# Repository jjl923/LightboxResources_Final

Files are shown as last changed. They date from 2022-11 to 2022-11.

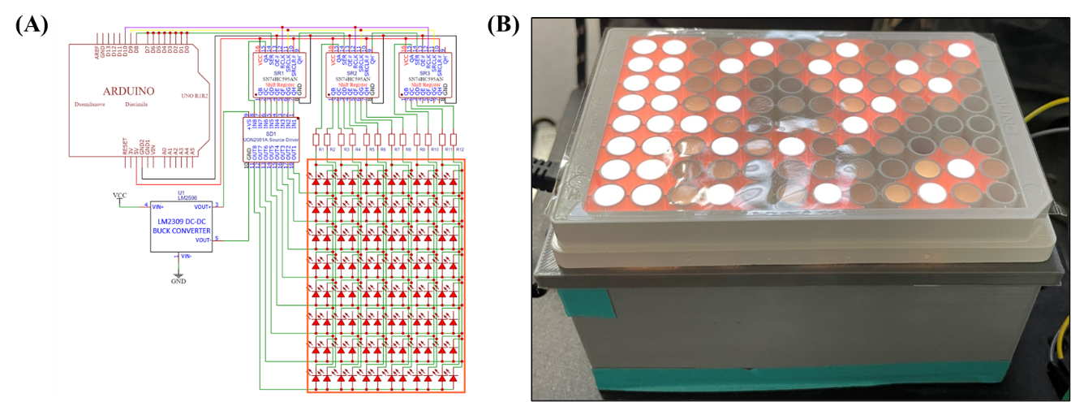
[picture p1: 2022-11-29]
Lightbox_Schematic.png

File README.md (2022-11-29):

# LightboxResources_Final

This repository contains all files necessary for building a lightbox with 96 multiplexed LEDS. To use any Python/Arduino scripts, ensure that the COM ports and fluorescence data file paths are changed to your specific setup. 

-STL Files are available for 3D printing a shell to contain all electronic components on the lightbox.

-Lightbox schematic shows the circuit diagram in which all components should be wired. 

-Python Files are used for fluorescence data analysis and sending data to the lightbox for lighting.
  - LightboxCalculator&Tester.py
    - tkinter interface that allows one to calculate the binary number to control each row of the lightbox. Click the LED in a row to be turned on, then click "Total". After doing so for each row, the final array should be input as "<a,b,c,d,r,f,g,h>" in the Python Script.
    
  - LBDataComm_NoFluorescence.py
    - Control the lighting profile of the lightbox using a manually input data array. Use the "LightboxCalculator&Tester.py" to determine the input array.
    
  - LBDataTest_FluorescenceXML.py
    - Use fluorescence data to control which LED is turned on. Two sets of sample data have been provided. Edit the clean_data() function and pass the file path of a given sample file.

  - FluorescenceAnalysisContinuous.ipynb
    - A jupyter notebook that can be used to continuously analyze sample data files in a given experiment. After running cells 1-3, cell 4 can be run over and over again with the sample file path name changed in order to simulate an automated fluorescence experiment. Of the sample data given, each experiment contains five timepoints with eight wells containing fluorescence data. So for example, run clean_data(r'C://...../SampleData1_1), then clean_data(r'C://...../SampleData1_2), then clean_data(r'C://...../SampleData1_3), etc.

-Arduino .ino files are uploaded to the Ardruino module used in the lightbox for PC communicationa and LED multiplexing.

-Lightbox PCB Files folder contains all output files for third-party manufacturers.

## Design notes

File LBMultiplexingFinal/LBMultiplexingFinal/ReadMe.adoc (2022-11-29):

:Author: jjljules
:Email: {AuthorEmail}
:Date: 12/11/2021
:Revision: version#
:License: Public Domain

= Project: {Project}

Describe your project

== Step 1: Installation
Please describe the steps to install this project.

For example:

1. Open this file
2. Edit as you like
3. Release to the World!

== Step 2: Assemble the circuit

Assemble the circuit following the diagram layout.png attached to the sketch

== Step 3: Load the code

Upload the code contained in this sketch on to your board

=== Folder structure

....
 sketch123                => Arduino sketch folder
  ├── sketch123.ino       => main Arduino file
  ├── schematics.png      => (optional) an image of the required schematics
  ├── layout.png          => (optional) an image of the layout
  └── ReadMe.adoc         => this file
....

=== License
This project is released under a {License} License.

=== Contributing
To contribute to this project please contact jjljules https://id.arduino.cc/jjljules

=== BOM
Add the bill of the materials you need for this project.

|===
| ID | Part name      | Part number | Quantity
| R1 | 10k Resistor   | 1234-abcd   | 10
| L1 | Red LED        | 2345-asdf   | 5
| A1 | Arduino Zero   | ABX00066    | 1
|===

=== Help
This document is written in the _AsciiDoc_ format, a markup language to describe documents.
If you need help you can search the http://www.methods.co.nz/asciidoc[AsciiDoc homepage]
or consult the http://powerman.name/doc/asciidoc[AsciiDoc cheatsheet]

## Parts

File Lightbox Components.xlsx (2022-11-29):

Component/Part | Price | Vendor | URL/Link
74HC595 Shift Register | $0.49 | Jameco Electronics | https://www.jameco.com/webapp/wcs/stores/servlet/ProductDisplay?productId=46105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
UDN2981A Source Driver | $3.95 | Jameco Electronics | https://www.jameco.com/webapp/wcs/stores/servlet/ProductDisplay?productId=1762681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
Arduino Uno | $26.73 | Amazon | https://www.amazon.com/Arduino-A000066-ARDUINO-UNO-R3/dp/B008GRTSV6
LM2596 Step Down Converter | $9.19 | Amazon | https://www.amazon.com/gp/product/B08L5VRBZS/ref=ppx_yo_dt_b_asin_title_o07_s00?ie=UTF8&psc=1
Jumper Wires | $2.10 | Digi-Key | https://www.digikey.com/en/products/detail/sparkfun-electronics/PRT-12796/5993861
Warm White LEDs (x1000) | $40.00 | Digi-Key | https://www.digikey.com/en/products/detail/creeled-inc/JK2835BWT-W-U30EB0000-N0000001/10820189
24 V Power Supply | $19.99 | Amazon | https://www.amazon.com/ALITOVE-100-240V-Adapter-Converter-5-5x2-1mm/dp/B01GC6VS8I
USB A-Male to B-Male Cable | $7.64 | Amazon | https://www.amazon.com/AmazonBasics-USB-Printer-Cable-Male/dp/B00NH13DV2?s=electronics

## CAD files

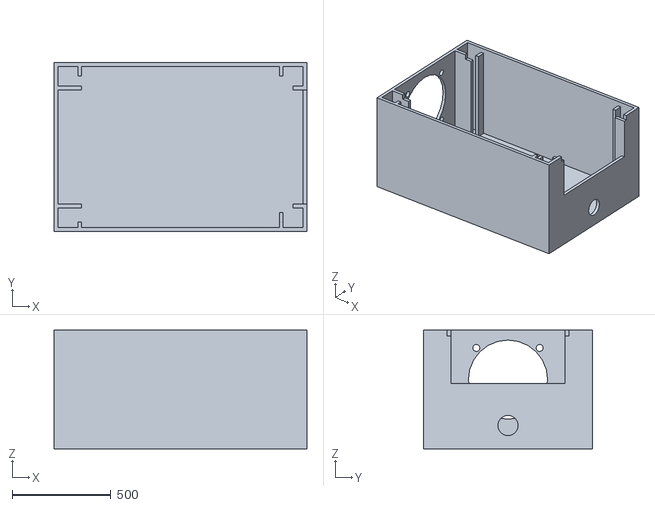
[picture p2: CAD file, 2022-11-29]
NewMultiplexLB_Base v1.stl
1278.0 x 855.0 x 600.4

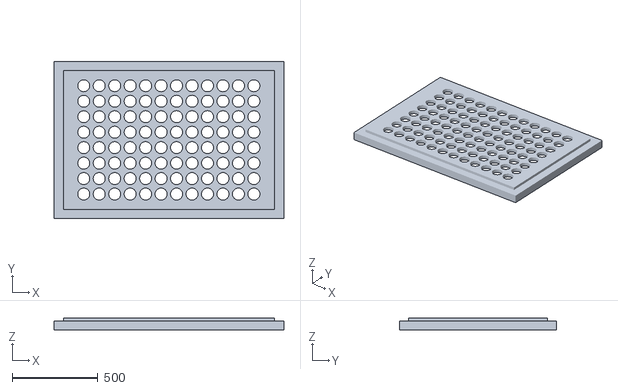
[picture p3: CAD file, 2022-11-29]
NewMultiplexLB_Top v1.stl
1338.0 x 915.0 x 71.6

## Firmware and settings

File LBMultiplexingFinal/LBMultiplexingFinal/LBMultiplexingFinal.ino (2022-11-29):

const int NUM_ROWS = 8;
const int NUM_COLS = 1;

const int dataPin = 8;
const int clockPin = 9;
const int latchPin=10;
int input_data[NUM_COLS][NUM_ROWS];
bool low_high[3];
byte bytedata[48];


int even_dataset[4][3] {
  {1,1,1},{0,0,0},{2,2,2},{0,0,0}
};

const byte numLEDs = 2;
byte ledPin[numLEDs] = {12, 13};
unsigned long LEDinterval[numLEDs] = {200, 400};
unsigned long prevLEDmillis[numLEDs] = {0, 0};

const byte buffSize = 40;
char inputBuffer[buffSize];
const char startMarker = '<';
const char endMarker = '>';
byte bytesRecvd = 0;
boolean readInProgress = false;
boolean newDataFromPC = false;

char messageFromPC[buffSize] = {0};
int newFlashInterval[12] {0,0,0,0,0,0,0,0,0,0,0,0};
float servoFraction = 0.0; // fraction of servo range to move

int data1_1 = 0;
int data1_2 = 0;
int data1_3 = 0;
int data2_1 = 0;
int data2_2 = 0;
int data2_3 = 0;
int data3_1 = 0;
int data3_2 = 0;
int data3_3 = 0;
int data4_1 = 0;
int data4_2 = 0;
int data4_3 = 0;

//int input_data[4][3] {{0,0,0},{0,0,0},{0,0,0},{0,0,0}};


unsigned long curMillis;

unsigned long prevReplyToPCmillis = 0;
unsigned long replyToPCinterval = 1000;

//=============

void setup() {
  Serial.begin(9600);
  
  delay(500);
  

  Serial.println("<Arduino is ready>");
  pinMode(clockPin, OUTPUT);
  pinMode(dataPin, OUTPUT);
  pinMode(latchPin, OUTPUT);
 
}


//=============

void loop() {
  curMillis = millis();
  getDataFromPC();
  replyToPC();
  int i=0;
  displayPixels(i,100);
  i++;
  if (i==NUM_ROWS) {i=1;}
  
}

//=============

void getDataFromPC() {
    
  if(Serial.available() > 0) {

    char x = Serial.read();
      
    if (x == endMarker) {
      readInProgress = false;
      newDataFromPC = true;
      //inputBuffer[bytesRecvd] = 0;
      parseData();
    }
    
    if(readInProgress) {
      inputBuffer[bytesRecvd] = x;
      bytesRecvd ++;
      if (bytesRecvd == buffSize) {
        bytesRecvd = buffSize - 1;
      }
    }

    if (x == startMarker) { 
      bytesRecvd = 0; 
      readInProgress = true;
    }
  }
}

//=============

void getDataFromPC2() {
    
  char input_data[15];
  if(Serial.available() >0) {
    for (int i=0; i<15; i++) {
      input_data[i] = Serial.read();
    }
    Serial.println(input_data);
  }
delay(100);
}

//=============
 
void parseData(){

   char * strtokIndx; // this is used by strtok() as an index
   char *strings[NUM_COLS][NUM_ROWS];
   char *ptr = NULL;

  
   ptr = strtok(inputBuffer,",");      // get the first part - the string
   while(ptr != NULL) {
    for(int i = 0; i < NUM_COLS; i++) {
     for (int j = 0; j<NUM_ROWS; j++) {
      strings[i][j] = ptr;  
      ptr = strtok(NULL, ",");
      //Serial.println(strings[i][j]); 
   }
  for(int i = 0; i < NUM_COLS; i++) {
     for (int j = 0; j<NUM_ROWS; j++) { 
    input_data[i][j] = atoi(strings[i][j]);
     }}

      


}
   }
}



//=============

void replyToPC(){

  if (newDataFromPC) {
    newDataFromPC = true;
    Serial.print("<Msg ");
    for(int i = 0; i < NUM_COLS; i++) {
     for (int j = 0; j<NUM_ROWS; j++) {
       Serial.println(input_data[i][j]);
    }
    }
    
    //Serial.print(curMillis >> 9); // divide by 512 is approx = half-seconds
    Serial.print(">");
  }}
  
void displayPixels(int val, int delay) {
  for (int i=0; i<delay; i++)
  {
    for(int row=0; row<NUM_ROWS; row++){
      int gcur = (input_data[val][row] & 65280)/256;
      int rcur = (input_data[val][row] & 255);
      digitalWrite(latchPin,LOW);
      shiftOut(dataPin,clockPin, MSBFIRST, 255-gcur);
      shiftOut(dataPin,clockPin, MSBFIRST, 255-rcur);
      shiftOut(dataPin,clockPin, MSBFIRST, B00000001 <<row);
      digitalWrite(latchPin, HIGH);
      
      delayMicroseconds(50);
      digitalWrite(latchPin,LOW);
      shiftOut(dataPin,clockPin, LSBFIRST, 255);
      shiftOut(dataPin,clockPin, LSBFIRST, 255);
      shiftOut(dataPin,clockPin, LSBFIRST, B00000001 <<row);
      digitalWrite(latchPin,HIGH);
      
    }
  }
}

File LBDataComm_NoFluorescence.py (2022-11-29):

#THIS VERSION IS TO USE THE LIGHTBOX AS A STANDALONE MODULE

import pandas as pd
import numpy as np
import xml.etree.ElementTree as ET
import serial
import time
print ()
print ()


#Set COM port depending on current user setup
serPort = 'COM6'
baudRate = 9600
ser = serial.Serial(serPort, baudRate)
startMarker = 60
endMarker = 62

def sendToArduino(sendStr):
    ser.write(sendStr.encode('utf-8')) # change for Python3


#======================================

def recvFromArduino():
    global startMarker, endMarker
    
    ck = ""
    x = "z" # any value that is not an end- or startMarker
    byteCount = -1 # to allow for the fact that the last increment will be one too many
    
    # wait for the start character
    while  ord(x) != startMarker: 
        x = ser.read()
    
    # save data until the end marker is found
    while ord(x) != endMarker:
        if ord(x) != startMarker:
            ck = ck + x.decode("utf-8") # change for Python3
            byteCount += 1
        x = ser.read()
    
    return(ck)


#============================

def waitForArduino():

    # wait until the Arduino sends 'Arduino Ready' - allows time for Arduino reset
    # it also ensures that any bytes left over from a previous message are discarded
    
    global startMarker, endMarker
    
    msg = ""
    while msg.find("Arduino is ready") == -1:

        while ser.inWaiting() == 0:
            pass
        
        msg = recvFromArduino()

        print (msg) # python3 requires parenthesis
        print ()
        
#======================================

def runTest(td):
    numLoops = len(td)
    waitingForReply = False

    n = 0
    while n < numLoops:
        teststr = td[n]

        if waitingForReply == False:
            sendToArduino(teststr)
            print ("Sent from PC -- LOOP NUM " + str(n) + " TEST STR " + teststr)
            waitingForReply = True

        if waitingForReply == True:

            while ser.inWaiting() == 0:
                pass
            
            dataRecvd = recvFromArduino()
            print ("Reply Received  " + dataRecvd)
            n += 1
            waitingForReply = False

            print ("===========")

        time.sleep(5)


#======================================


def blockshaped(arr, nrows, ncols):
    """
    Return an array of shape (n, nrows, ncols) where
    n * nrows * ncols = arr.size

    If arr is a 2D array, the returned array should look like n subblocks with
    each subblock preserving the "physical" layout of arr.
    """
    h, w = arr.shape
    assert h % nrows == 0, "{} rows is not evenly divisble by {}".format(h, nrows)
    assert w % ncols == 0, "{} cols is not evenly divisble by {}".format(w, ncols)
    return (arr.reshape(h//nrows, nrows, -1, ncols)
               .swapaxes(1,2)
               .reshape(-1, nrows, ncols))



print ("Serial port " + serPort + " opened  Baudrate " + str(baudRate))
waitForArduino()
#Data sent to the Arduino for Lighting
a = [4095, 4095,4095,4095,4095,4095,4095,4095]
b = '<'+ ','.join(map(str, a)) + '>'
testData = [b]

runTest(testData)


ser.close()
 



 
